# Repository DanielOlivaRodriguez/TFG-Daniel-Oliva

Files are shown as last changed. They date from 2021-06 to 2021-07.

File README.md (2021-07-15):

# TFG Daniel Oliva Rodríguez
## "*Sistema de adquisición fisiológica de los agentes de seguridad y emergencias*"

### **Grado en Ingeniería en Tecnologías Industriales, Universidad Rey Juan Carlos**

------

#### RESUMEN DEL PROYECTO

En este Trabajo Fin de Grado se ha diseñado un dispositivo de adquisición de datos fisiológicos para agentes de seguridad y emergencias.

En primer lugar, se investigó qué parámetros se debían monitorizar para obtener una visión completa del estado de salud del agente de seguridad. Los parámetros seleccionados fueron las pulsaciones por minuto, saturación de oxígeno, temperatura, electrocardiograma y fuerzas g.

En segundo lugar, se diseñó el dispositivo basando su funcionamiento en 4 módulos:

+ Módulo de adquisición de datos: este módulo está compuesto por un Arduino UNO, un Arduino Nano IOT 33 y los distintos sensores que recogen los datos fisiológicos.
+ Módulo de gestión de datos: formado por una Raspberry Pi 4 que será la que reciba los datos de los arduinos y los almacene en una BBDD.
+ Módulo de visualización de datos: formado por software empleado para la visualización de datos a través de un navegador web o aplicación móvil. Dicho software se instala en la Raspberry Pi 4.
+ Módulo de alimentación: formado por una batería externa USB que alimenta a la Raspberry Pi 4.

<p algin="center">
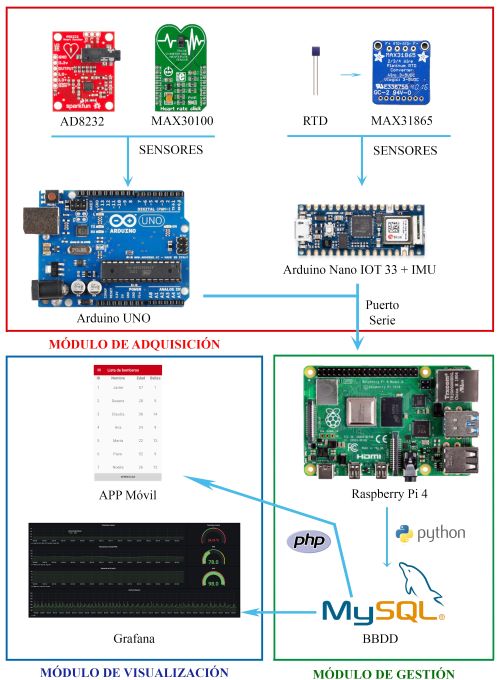
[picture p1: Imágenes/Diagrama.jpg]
    
</p>
Como se puede ver en la imagen, los Arduinos recogen los datos adquiridos por los sensores y los envían a la Raspberry mediante el puerto serie. Desde la Raspberry, ejecutando los códigos de Python, se leen los datos que recibe y se suben a la BBDD. Posteriormente, mediante un *dashboard* en Grafana, es posible visualizar los datos recogidos por el dispositivo. Además, también se puede acceder a los datos a través de la aplicación programada en Android.

-----

#### ORGANIZACIÓN DE LOS ARCHIVOS

##### **App** 

En esta carpeta se encuentra el instalador APK de la aplicación móvil así como el proyecto de Android Studio contenido en un *.zip* en el que se encuentra toda la programación de la aplicación.

##### **Arduino** 

En esta carpeta se almacenan los códigos usados en el Arduino UNO y el Arduino Nano IOT 33.

##### **BBDD**

En esta carpeta se encuentran los archivos realizados en MySQL Workbench para la creación de la BBDD.

##### Comité Ética

En esta carpeta se encuentra el consentimiento informado que firmaron los participantes para realizar las evaluaciones.

##### **Imágenes**

Las imágenes del proyecto.

##### **PHP**

En esta carpeta se alojan los códigos PHP usados para la subida y consulta de datos a la BBDD a través de la aplicación móvil.

##### **Python**

Estos códigos se ejecutan en la Raspberry y sirven para subir los datos recogidos por los Arduinos a la BBDD.

##### Resultados

En esta carpeta se encuentran los resultados de las pruebas. Además, el documento "marcas de tiempo" contiene las marcas de tiempo a la que suceden los distintos hitos. Los resultados se dividen a su vez en dos carpetas:

+ UNO: Resultados de pulsioximetría y ECG.

+ NANO: Resultados de temperatura y fuerzas g.

##### **Soporte 3D**

En esta carpeta se encuentran los archivos de AutoCAD con el diseño del soporte 3D para el sensor de pulsioximetría así como los planos.

---

#### MATERIAL EMPLEADO

El material empleado para la realización del proyecto ha sido:

+ Arduino UNO
+ Arduino Nano IOT 33
+ Sensor de temperatura Heraeus M222
+ Circuito amplificador Adafruit Pt1000 MAX31865
+ Sensor pulsioximetría MIKROE Heart Rate Click MAX30100
+ Sensor ECG SparkFun AD8232
+ Raspberry Pi 4
+ Batería externa USB

----------

#### SOFTWARE EMPLEADO

El software empleado a lo largo de todo el proyecto ha sido:

+ Arduino IDE: para la programación de los arduinos.
+ AutoCAD: para el diseño del soporte 3D para el sensor de pulsioximetría.
+ EAGLE PCB: para el diseño de la PCB.
+ phpMyAdmin: para la gestión y depuración de errores de la BBDD.
+ MySQL Workbench: para la creación y diseño de la BBDD.
+ Android Studio: para la programación de la aplicación móvil Android.
+ Grafana: para la creación del panel para la visualización de los resultados.

------

#### DISEÑO PCB

Para el diseño de la PCB se ha empleado el software EAGLE PCB.

El diseño de las pistas es el siguiente:

<p algin="center">
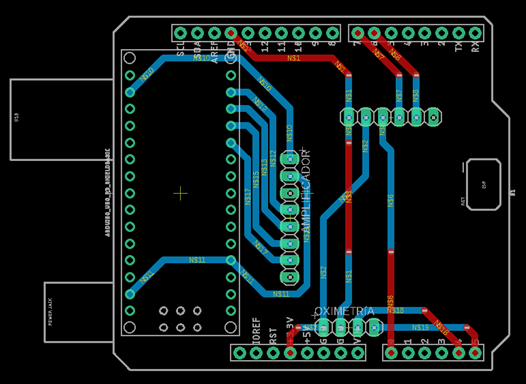
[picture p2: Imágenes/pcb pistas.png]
    
</p>

Y el resultado final:

<p algin="center">
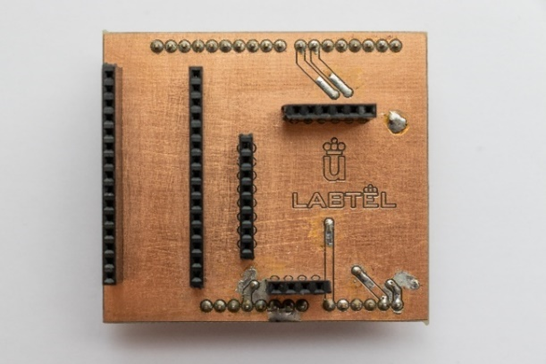
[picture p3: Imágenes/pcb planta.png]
    
</p>

<p algin="center">
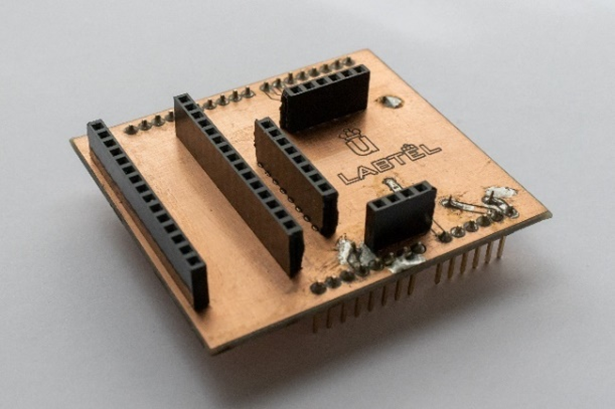
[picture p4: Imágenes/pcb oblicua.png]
    
</p>

Montada sobre el Arduino UNO:

<p algin="center">
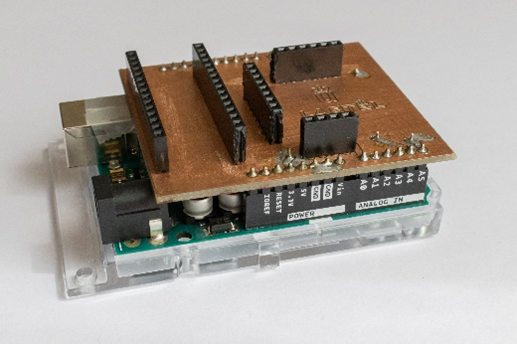
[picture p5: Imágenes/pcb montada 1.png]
    
</p>

Y con todos los componentes:

<p algin="center">
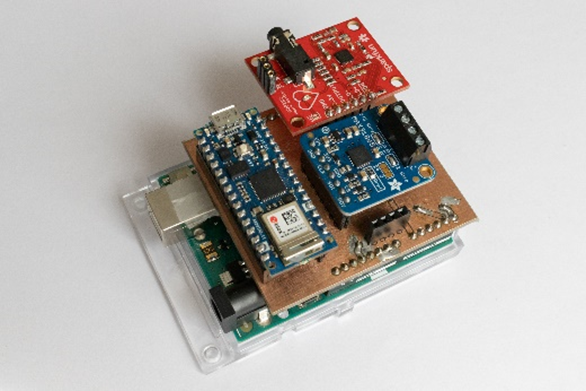
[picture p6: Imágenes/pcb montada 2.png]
    
</p>

----

#### DISEÑO SOPORTE 3D

Se ha fabricado un soporte para colocarlo sobre el dedo del usuario y que sea más sencillo tomar los datos con el sensor de pulsioximetría.

Este es el resultado final:

<p algin="left">
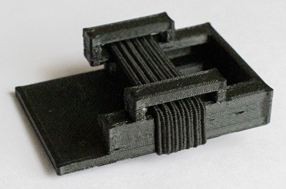
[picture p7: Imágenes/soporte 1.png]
    
</p>

<p algin="center">
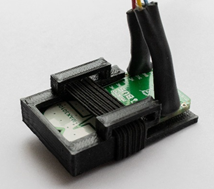
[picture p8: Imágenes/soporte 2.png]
    
</p>

<p algin="right">
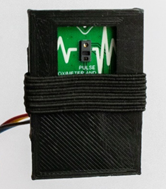
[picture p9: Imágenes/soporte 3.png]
    
</p>

-----

#### PANEL DE GRAFANA

A continuación, se muestra el panel empleado para la visualización de datos en el trabajo.

<p algin="center">
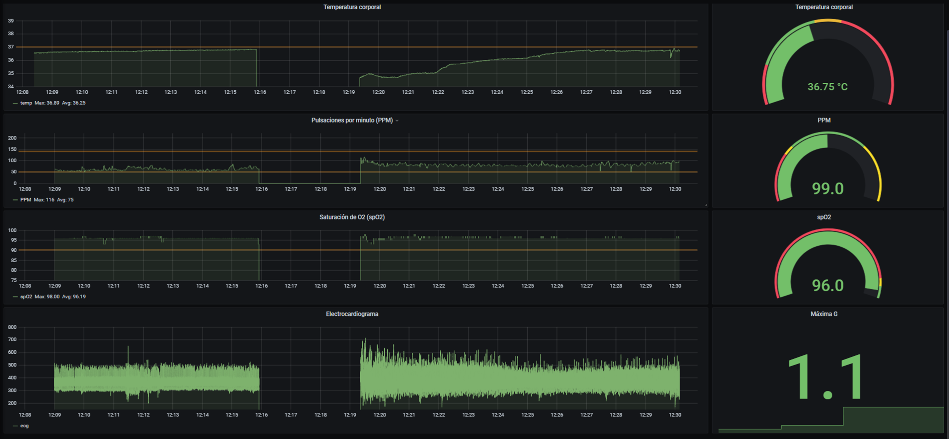
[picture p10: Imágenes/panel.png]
    
</p>

En la primera fila, se encuentra la gráfica temporal de la temperatura junto con la última temperatura tomada.

En la segunda y tercera fila, lo mismo que en la anterior pero para las pulsaciones por minuto y la saturación de oxígeno en sangre, respectivamente.

En la cuarta fila se encuentra el electrocardiograma y la máxima fuerza g registrada por el dispositivo.

Al ampliar el electrocardiograma, puede observarse la onda.

<p algin="center">
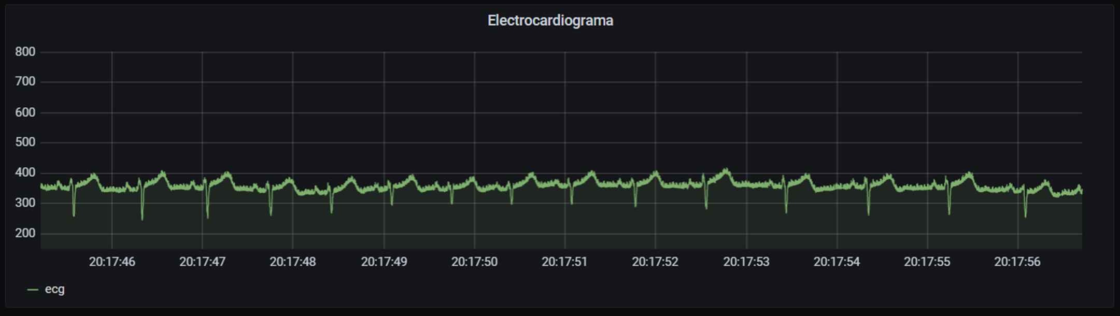
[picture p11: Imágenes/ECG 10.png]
    
</p>

-----

#### RESULTADOS

A continuación, se muestran los resultados obtenidos durante las evaluaciones.

Las evaluaciones se llevaron a cabo a lo largo de varios días en el Centro Unificado de Seguridad (CUS) de Alcorcón con la colaboración de la Jefatura de Bomberos de Alcorcón. Se tomaron datos de 10 voluntarios.

Las evaluaciones tenían una duración aproximada de media hora y se dividían en distintos intervalos:

<p algin="center">
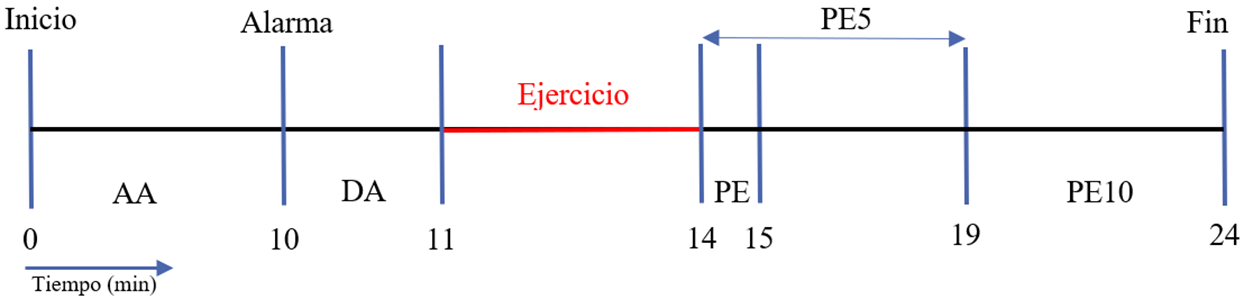
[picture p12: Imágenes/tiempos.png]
    
</p>

+ AA: tramo anterior a la activación de la alarma.
+ DA: tramo posterior a la activación de la alarma.
+ PE: intervalo de 1 minuto justo después de realizar ejercicio físico.
+ PE5: intervalo de 5 minutos posterior a la realización de ejercicio físico.
+ PE10: intervalo de 5 minutos después del intervalo anterior.

Los resultados pueden encontrarse en formato excel en la carpeta Resultados.

A continuación, se muestran en forma de gráfico:

Pulsaciones por minuto:

<p algin="center">
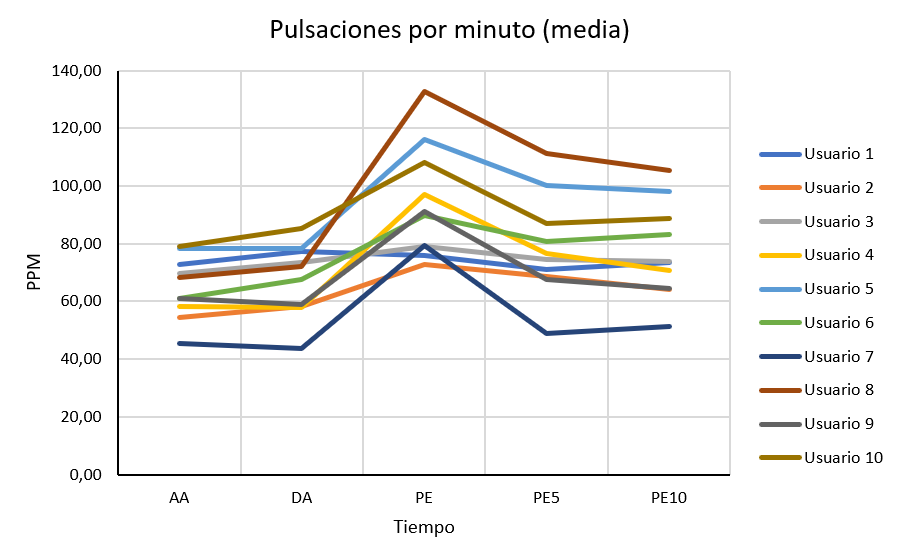
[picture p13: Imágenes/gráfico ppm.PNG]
    
</p>

Saturación de oxígeno en sangre:

<p algin="center">
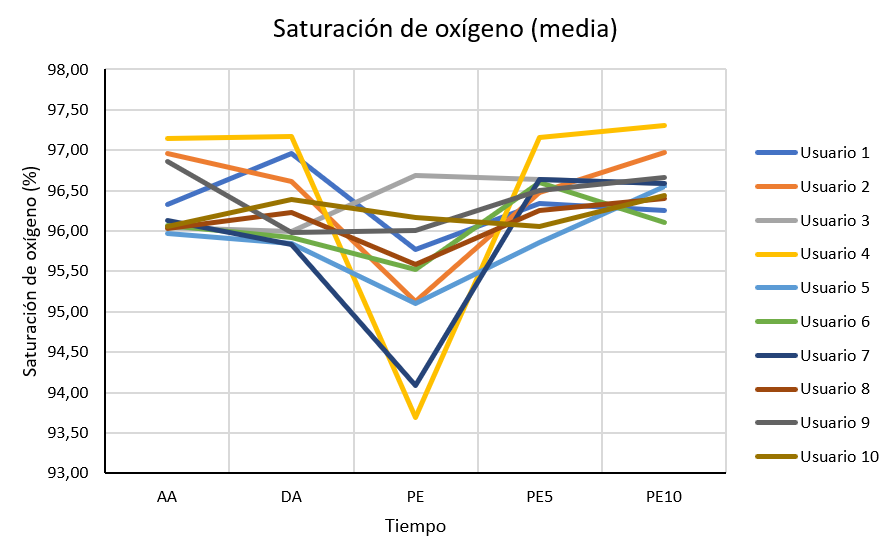
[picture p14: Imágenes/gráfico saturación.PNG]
    
</p>

Temperatura:

<p algin="center">
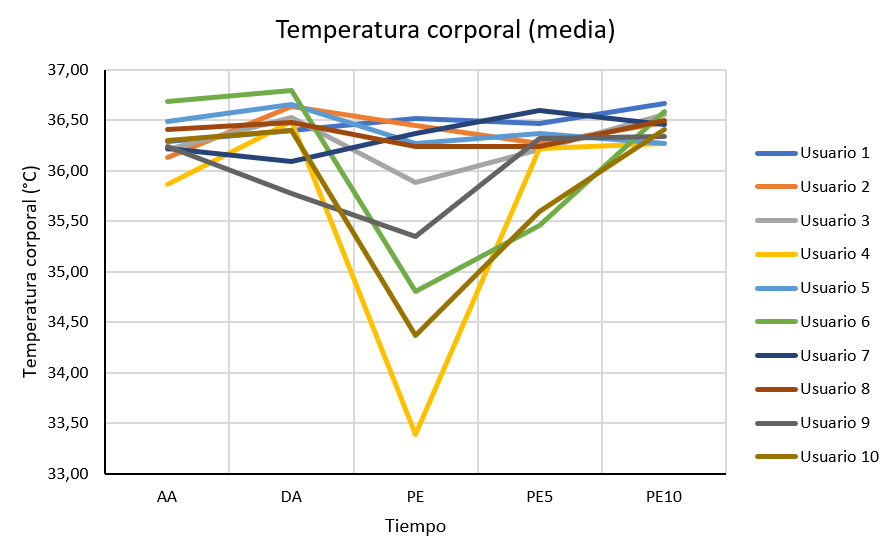
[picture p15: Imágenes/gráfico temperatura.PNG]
    
</p>

Las gráficas del ECG pueden verse en el siguiente apartado.

-------

#### GRÁFICAS ECG

Usuario 1

<p algin="center">
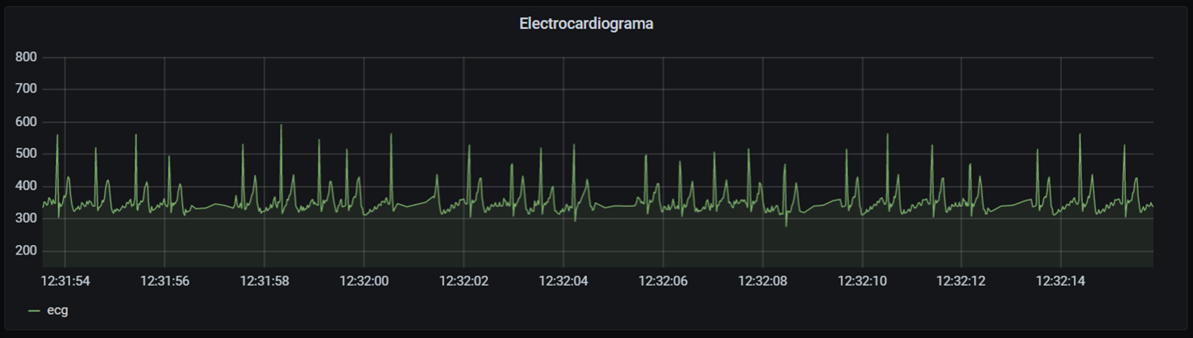
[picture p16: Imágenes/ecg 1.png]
    
</p>

Usuario 2

<p algin="center">
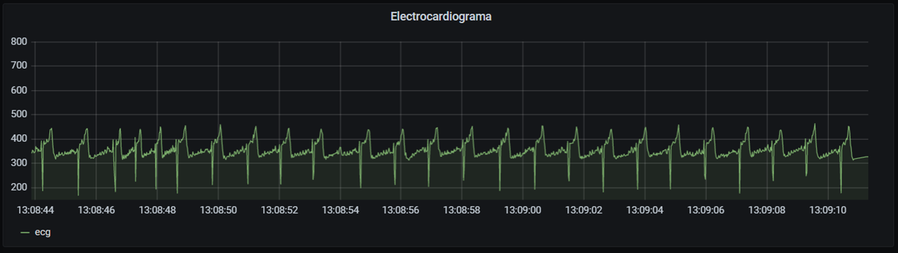
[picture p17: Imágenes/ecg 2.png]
    
</p>

Usuario 3

<p algin="center">
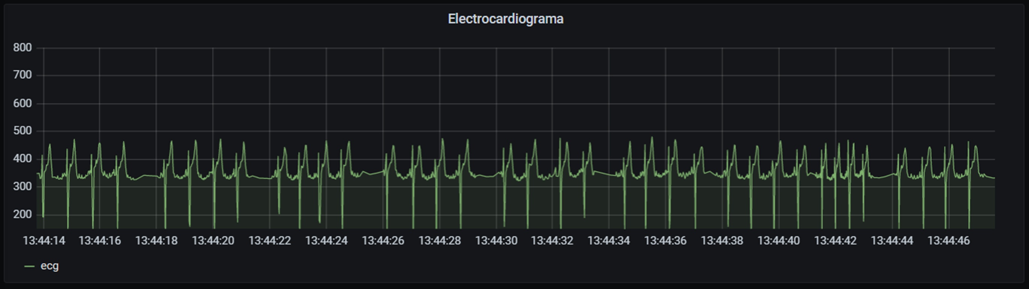
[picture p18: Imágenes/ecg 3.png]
    
</p>

Usuario 4

<p algin="center">
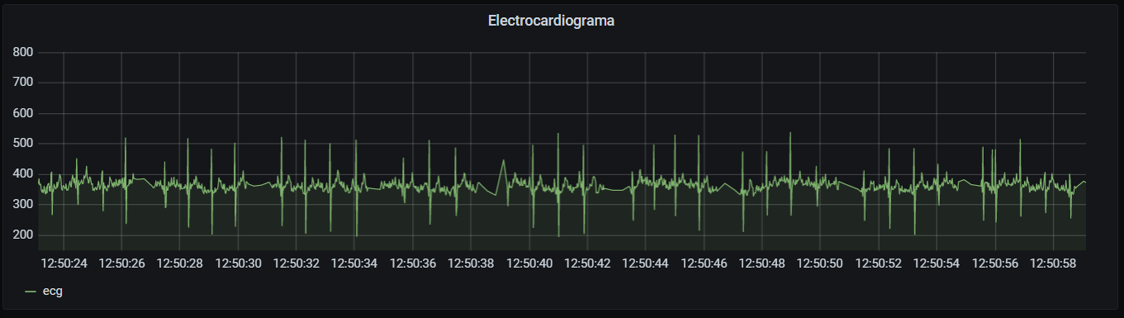
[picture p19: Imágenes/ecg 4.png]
    
</p>

Usuario 5

<p algin="center">
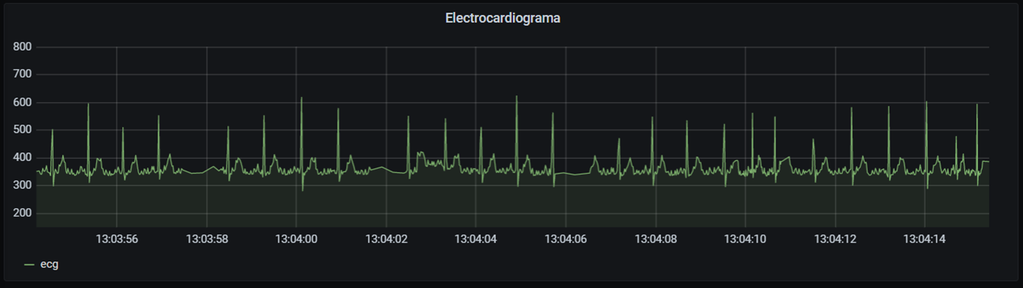
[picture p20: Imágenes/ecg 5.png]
    
</p>

Usuario 6

<p algin="center">
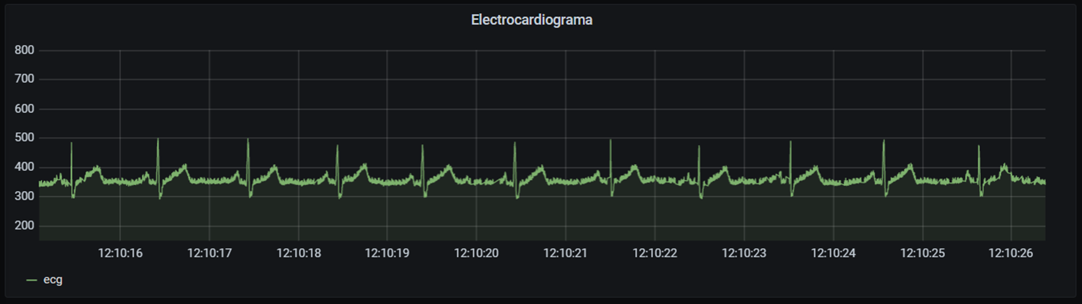
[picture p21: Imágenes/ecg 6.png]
    
</p>

Usuario 7

<p algin="center">
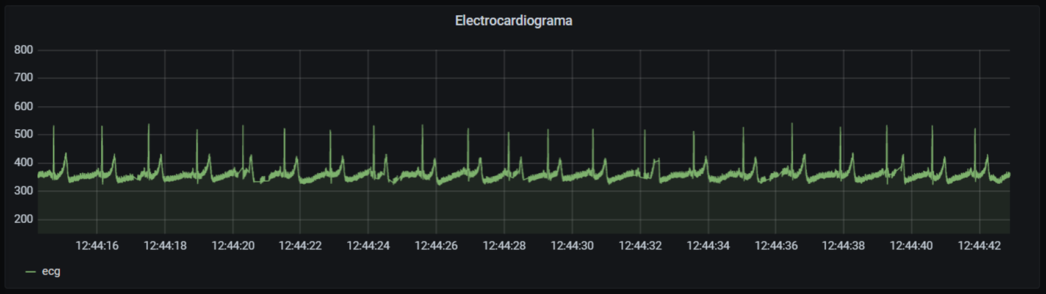
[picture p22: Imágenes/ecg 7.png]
    
</p>

Usuario 8

<p algin="center">
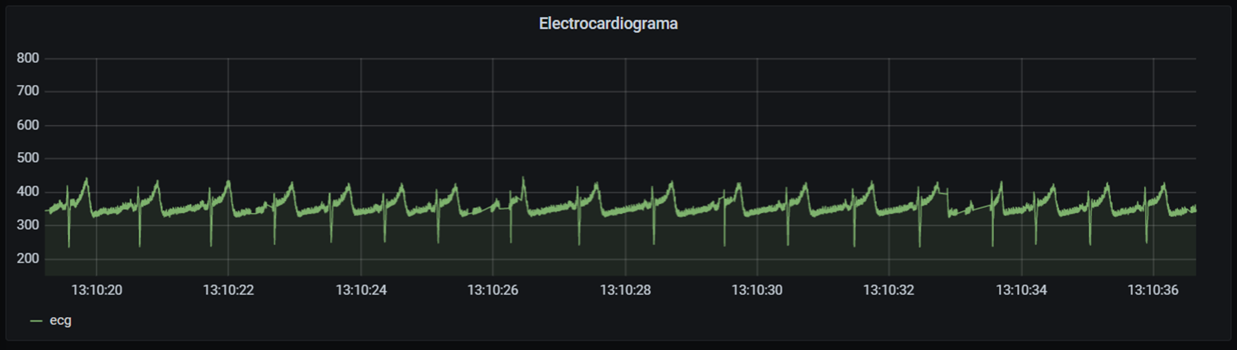
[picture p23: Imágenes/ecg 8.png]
    
</p>

Usuario 9

<p algin="center">
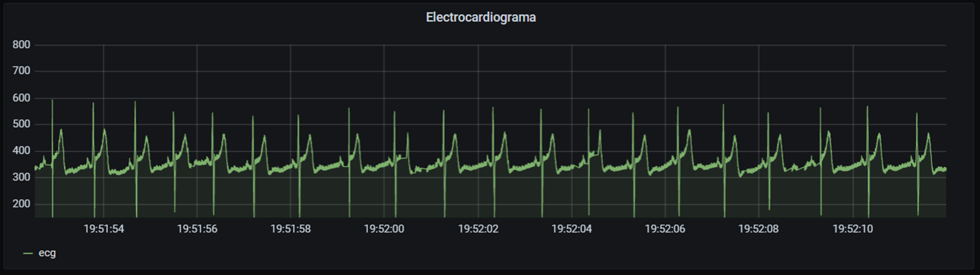
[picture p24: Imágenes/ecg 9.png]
    
</p>

Usuario 10

<p algin="center">
    
</p>

----------------

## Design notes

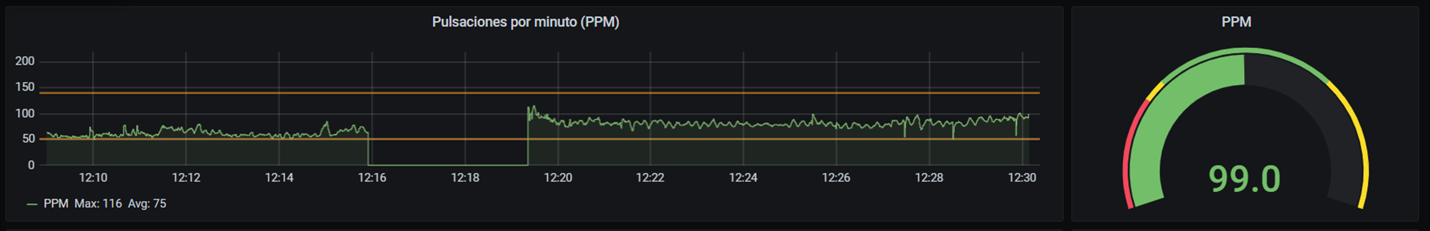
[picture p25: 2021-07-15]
Imágenes/ppm.png

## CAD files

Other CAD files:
Soporte 3D/Soporte_pulsioxímetro_planos.dwg
Soporte 3D/Soporte_pulsioxímetro.dwg
Soporte 3D/Soporte_pulsioxímetro_fusion.f3d

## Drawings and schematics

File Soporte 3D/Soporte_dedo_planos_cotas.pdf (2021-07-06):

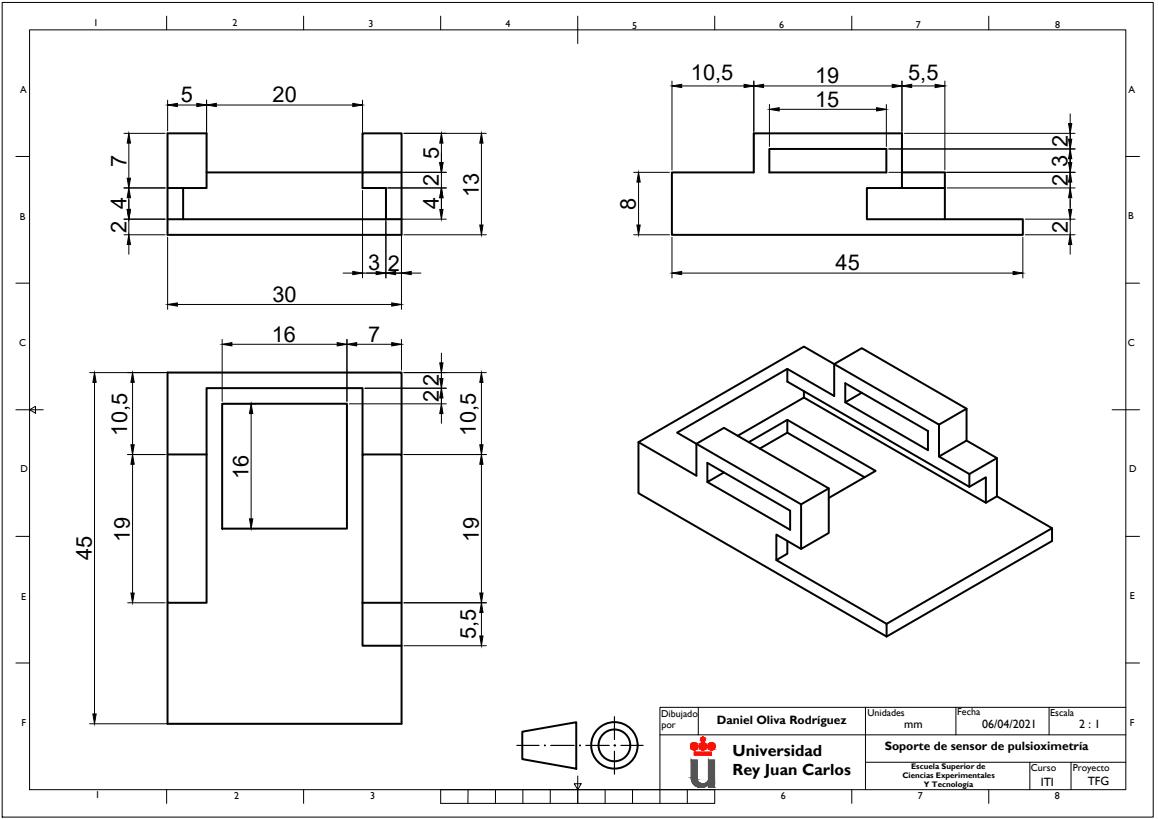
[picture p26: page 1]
Dibujado por; Unidades; Fecha; Escala Escuela Superior de; Curso; Proyecto Ciencias Experimentales Y Tecnología Daniel Oliva Rodríguez; Soporte de sensor de pulsioximetría 1; 8 ABCDEF; ABCDEF Universidad Rey Juan Carlos; 2 : 1 ITI; TFG 2 2 8

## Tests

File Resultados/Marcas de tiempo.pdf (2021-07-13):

Usuario | Inicio prueba | Alarma | Inicio ejercicio | Vuelta del ejercicio | Fin prueba
1 | 2021-05-07 10:25:33.967 | 2021-05-07 10:31:56.068 | 2021-05-07 10:34:57.584 | 2021-05-07 10:43:33.554 | 2021-05-07 10:54:08.872
2 | 2021-05-07 11:01:25.798 | 2021-05-07 11:09:56.267 | 2021-05-07 11:11:00.614 | 2021-05-07 11:15:55.027 | 2021-05-07 11:25:05.477
3 | 2021-05-07 11:29:54.683 | 2021-05-07 11:36:04.120 | 2021-05-07 11:38:10.044 | 2021-05-07 11:42:33.106 | 2021-05-07 11:53:00.761
4 | 2021-05-25 10:31:44.155 | 2021-05-25 10:37:00.128 | 2021-05-25 10:39:39.198 | 2021-05-25 10:43:37.959 | 2021-05-25 10:52:18.910
5 | 2021-05-25 10:58:16.618 | 2021-05-25 11:04:48.727 | 2021-05-25 11:06:09.114 | 2021-05-25 11:11:04.494 | 2021-05-25 11:20:59.054
6 | 2021-05-31 10:08:59.826 | 2021-05-31 10:14:50.010 | 2021-05-31 10:15:55.105 | 2021-05-31 10:19:21.208 | 2021-05-31 10:30:08.592
7 | 2021-05-31 10:41:26.314 | 2021-05-31 10:49:00.083 | 2021-05-31 10:49:33.805 | 2021-05-31 10:52:31.868 | 2021-05-31 11:03:31.748
8 | 2021-05-31 11:08:28.787 | 2021-05-31 11:15:35.002 | 2021-05-31 11:16:58.028 | 2021-05-31 11:20:22.278 | 2021-05-31 11:33:43.259
9 | 2021-06-01 17:49:25.736 | 2021-06-01 17:57:32.507 | 2021-06-01 17:58:49.217 | 2021-06-01 18:00:54.678 | 2021-06-01 18:11:02.673
10 | 2021-06-01 18:14:43.389 | 2021-06-01 18:19:29.665 | 2021-06-01 18:20:30.316 | 2021-06-01 18:22:20.071 | 2021-06-01 18:33:44.208

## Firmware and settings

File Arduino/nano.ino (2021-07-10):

// Este código obtiene la temperatura y los valores de aceleración y velocidad desde el Arduino Nano IOT 33

// Librería del circuito amplificador de temperatura
#include <Adafruit_MAX31865.h>
// Librería del sensor IMU
#include <Arduino_LSM6DS3.h>

// Configuración del circuito amplificador
// Use software SPI: CS, DI, DO, CLK
Adafruit_MAX31865 thermo = Adafruit_MAX31865(8, 9, 10, 11);
// use hardware SPI, just pass in the CS pin
//Adafruit_MAX31865 thermo = Adafruit_MAX31865(10);

// Resistencia de referencia. PT100 = 430 ; PT1000 = 4300
#define RREF      4300.0
// Resistencia nominal a 0ºC. PT100 = 100 ; PT1000 = 1000
#define RNOMINAL  1000.0

// Se definen las variables del IMU
float aX, aY, aZ; // Aceleración (g)
float gX, gY, gZ; // Velocidad angular (º/s)
float maxG; // Máxima fuerza G sufrida
float aT; // Aceleración total
// Variables auxiliares para calcular el máximo
float maxGAux1;
float maxGAux2;

//Variables del sensor de temperatura
float ratio;
float resistencia;
float temp;

//Variable para el intercambio de datos con la raspberry
String cad;

// ID del dispositivo
#define dispositivo_id  1

void setup() {
  // Inicialización del puerto serie
  Serial.begin(115200);
  // Se definen el número de cables del sensor de temperatura
  thermo.begin(MAX31865_2WIRE);  // MAX31865_2WIRE = 2 cables ; MAX31865_3WIRE = 3 cables ; MAX31865_3WIRE = 3 cables
  // Inicialización del IMU
  if (!IMU.begin()) {
    while (true);
  } 
}

void loop() {
  
  // TEMPERATURA
  // La siguiente parte de código calcula el ratio y la resistencia del sensor de temperatura
  // Se comenta porque no lo necesitamos
  /*  
      uint16_t rtd = thermo.readRTD();
      // Se calcula el ratio
      ratio = rtd;
      ratio /= 32768;
      //Se calcula la resistencia
      resistencia = RREF*ratio;
  */
  // Se calcula la temperatura
  temp = thermo.temperature(RNOMINAL, RREF);
  temp = temp + 1.5;
      
  // Se hacen las mediciones del IMU
  IMU.readAcceleration(aX, aY, aZ);
  IMU.readGyroscope(gX, gY, gZ);

  // Se calcula la aceleración total
  aT = sqrt(pow(aX,2)+pow(aY,2)+pow(aZ,2));

  // Se calcula la máxima fuerza G que mide el sensor
  maxG = max(maxG,aT);          // Máximo de aT y el valor anterior de maxG

  // Se define la cadena para el intercambio de datos
  cad = "#1:" + String(temp)+ "#2:" + String(aX)+ "#3:" + String(aY)+ "#4:" + String(aZ)+ "#5:" + String(gX)+ "#6:" + String(gY)+ "#7:" + String(gZ)+ "#8:" + String(maxG)+ "#9:" + String(dispositivo_id)+ "@";
    
  // Se imrpime la cadena por el puerto serie
  Serial.println(cad);
  delay(500);
}

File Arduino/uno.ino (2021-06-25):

// Este código obtiene los valores de pulso y oxígeno en sangre junto con el electrocardiograma desde el Arduino UNO

// SENSOR DE PULSO Y OXIMETRÍA
#include <Wire.h>
#include "MAX30100_PulseOximeter.h"
#define REPORTING_PERIOD_MS     10
PulseOximeter pox;
 
// DECLARACIÓN DE VARIABLES
float ppm; //Variable en la que se almacenan las pulsaciones por minuto
int spO2; //Variable en la que se almacena la saturación de oxígeno
int ecg; //Variable en la que se almacena el electrocardiograma
String cad; // Cadena para el intercambio de datos con la raspberry

// ID del dispositivo
#define dispositivo_id  1

void setup() {
  
  // Inicializamos el puerto serie
  Serial.begin(2000000);

  //Iniciamos el pulsioximetro
  if (!pox.begin()) {
        //Serial.println("FAILED");
        for(;;);
    } else {
        //Serial.println("SUCCESS");
    }

  // Inicializamos los pines del ECG
  pinMode(6, INPUT); // Setup for leads off detection LO +
  pinMode(7, INPUT); // Setup for leads off detection LO -
}

void loop() {
    // Actualizamos el pulsioxímetro
    pox.update(); 
    
    // Obtenemos los valores de pulsaciones y saturación de O2 en sangre
    ppm = pox.getHeartRate();
    spO2 = pox.getSpO2();
    
    // Valor del ECG
    ecg = analogRead(A0);
    
    // Se establecen los valores dentro de la cadena
    //cad = "#1:" + String(ppm)+ "#2:" + String(spO2)+ "#3:" + String(ecg)+ "#4:" + String(dispositivo_id)+ "@";
    cad = "#1:" + String(ppm)+ "#2:" + String(spO2)+ "#3:" + String(ecg)+ "#4:" + String(dispositivo_id);
    // Imprimimos la cadena
    Serial.println(cad);
    delay(2);
}

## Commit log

2021-06-25 Se inicia el proyecto
2021-07-06 Soporte 3D
    [Soporte_dedo.dwg, Soporte_dedo_fusion.f3d, Soporte_dedo_planos.dwg]
2021-07-13 marcas de tiempo
